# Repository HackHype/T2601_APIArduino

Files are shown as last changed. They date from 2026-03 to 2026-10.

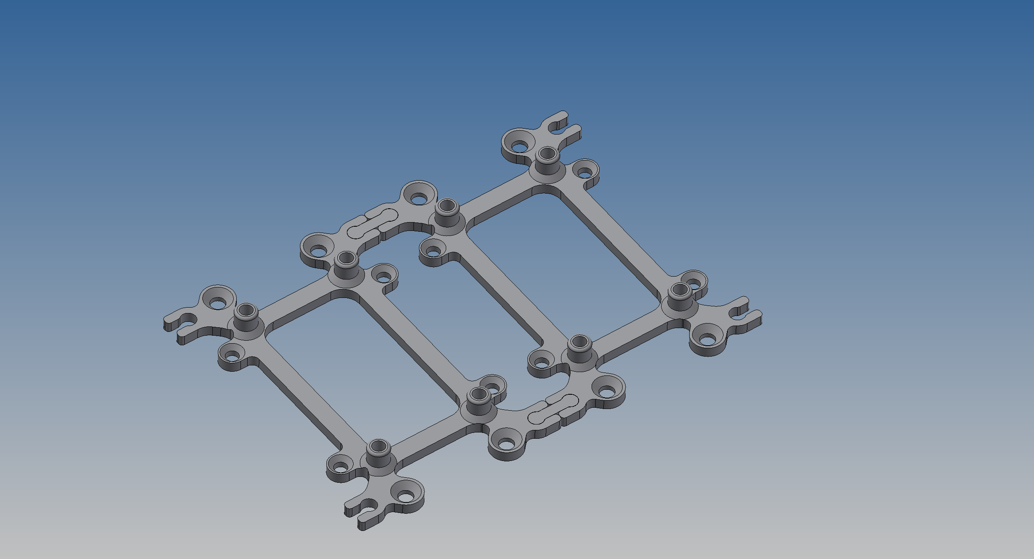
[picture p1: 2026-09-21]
T2601_Mecanique/T2601_EG2.png

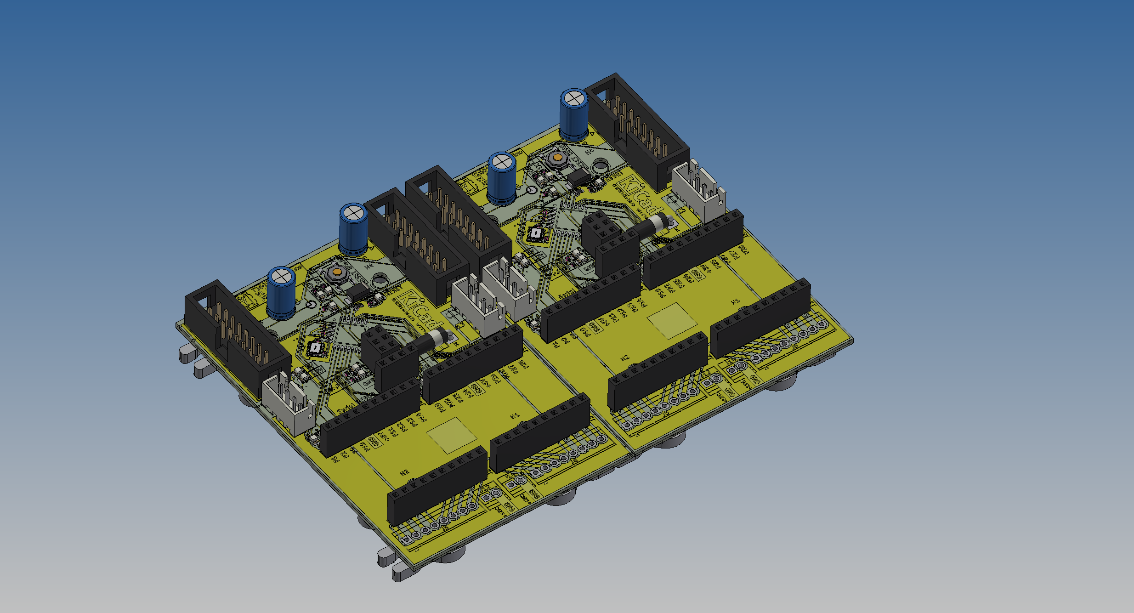
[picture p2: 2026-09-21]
T2601_Mecanique/T2601_EG.png

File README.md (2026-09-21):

# T2601 — API Arduino
> Modular I/O expansion board based on the ATmega328PB.






---

## System Architecture

### 🟦 Main Board
_Mother board of the system — orchestrates the entire bus_

- Hosts a compact dev board (Teensy-style)
- **3 Mezzanine slots** for I/O interface cards
- **N System Mezzanine slots** for advanced modules
  - FRAM / RTC / MicroSD / ... modules
- Power management for the entire system

---

### 🟩 Extension Board
_Bus slave node — based on the ATmega328P_

- Microcontroller: **ATmega328P**
- **2 Mezzanine slots** for I/O
- **Chained UART** communication across all extension boards
- Programming via **Arduino as ISP**

---

### 🟨 Mezzanine Card
_swappable I/O interface module — 25 × 25 mm_

| Driver | Type | Typical Use |
|---|---|---|
| ULN2803 | Sink NPN | Relays, inductive loads |
| MIC2981 | Source PNP  | High-voltage loads |
| MOSFET | Switch | Power loads |
| Voltage divider| Passive | Analog input |
| Optocoupler | Isolated | Galvanic isolation |

---

## Repository Structure
```
T2601_APIArduino/
├── hardware/
│   ├── main_board/        # Main board
│   ├── extension_board/   # ATmega328P extension board
│   └── mezzanine/         # I/O mezzanine cards
├── firmware/              # Arduino code
├── docs/                  # Schematics, datasheets
└── README.md
```

---

## License

This project is open hardware — **CERN OHL v2 Strongly Reciprocal**.

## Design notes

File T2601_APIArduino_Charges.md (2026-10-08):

# T2601 API Arduino

# Carte Extension

## Généralité

Basé sur microcontroler Atmega 328PB
Emplacement pour 2 mezanine.

## Connectivité

UART circulaire
Bus de logique avec nappe et connecteur de nappe 2x8  
4x 5V (pour 1,5 A), 6x GND, 2x UART (aller et retour), 1x rst, 1x res  
Bus puissance avec connecteurs JST  
2x 12V 2xGND (pour 2A)  
Les GND logique et puissance sont séparer  
Alimentation puissance par borniers à vis  
1x 12V 1xGND  
16 Sortie puissance par borniers à vis, 1 bornier par mezzanine  
Connexion pour la programmation par pin socket 2x3  
Connexion pour le debug (SoftwareSerial) par pin socket 1x4  
1x GND 1x TX 1x RX 1x statut

## Fonctionnalité

Led vertes sur chacune des alimentations  
Led jaune sur pin prog  
Led jaune sur RX TX  
Led vertes sur chacune des I/O  
Led rouge sur la dernière broche libre de l’arduino

## Pinout µc

|Pin|Fonction|Utilisation|
|-|-|-|
|1 |PWM |Mezz 1 (PWM)|
|2 | |led (couleur à définir) + generale debug pin|
|3 |SDA + |led (couleur à définir)|
|4 |VCC |Alimentation|
|5 |GND |Alimentation|
|6 |SCL |led (couleur à définir)|
|7 |XTAL1 |Crystal|
|8 |XTAL2 |Crystal|
|9 |PWM |Mezz 1 (PWM)|
|10|PWM AIN0 |Mezz 1 (PWM)|
|11|AIN1 |Mezz 1|
|12| |Mezz 1|
|13|PWM |Mezz 1 (PWM)|
|14|PWM SS |Mezz 1 (PWM)|
|15|MOSI TXD1 +|Programmation|
|16|MISO RXD1  |Programmation|
|17|SCK |Programmation|
|18|AVCC |Alimentation|
|19|ADC6 SS1 |Mezz 2 (Analog)|
|20|AREF |Alimentation|
|21|GND |Alimentation|
|22|ADC7 MOSI1 |Mezz 2 (Analog)|
|23|ADC0 MISO1 |Mezz 2 (Analog)|
|24|ADC1 SCK1  |Mezz 2 (Analog)|
|25|ADC2 |Mezz 2 (Analog)|
|26|ADC3 |Mezz 2 (Analog)|
|27|ADC4 SDA |Mezz 2 (Analog)|
|28|ADC5 SCL |Mezz 2 (Analog)|
|29|Reset||
|30|RXD PWM |Communication|
|31|TXD PWM |Communication|
|32|PWM + |Mezz 1 (PWM)|

_+ : d'autre fonction sont disponibles mais pas utilisées_

_les interruptions ne sont pas notées dans les fonctions_

## Mécanique

Largeur 60, Hauteur 90 à définir
4 trous pour vis M3 avec un entraxe de 30 en largeur, à 10 du bord suppérieur et à 20 du bord inférieur.

# Mezanine

1 connecteur pin header male 1x10
1x GND, 1x 5V, 8x logique,  
1 connecteur pin socket femelle 1x10  
1x GND, 1x 12V, 8x puissance,

## Types

* OUTPUT

  * ULN2803
  * MIC2981
  * Mosfet
  * Optocoupleur
  * Pont (5V direct)
* INPUT

  * Pont diviseur 12/24V
  * Pont (5V direct)
  * Optocoupleur (autre sens)
* IO

  * Loconet (nécessite ICP pin)
  * Carte SD + RTC (nécessite SPI ou I2C)
  * RS485 (nécessite Software serial)
  * FRAM (nécessite SPI ou I2C)

## communication (idée)

Commandes envoyée ddans le Bus

|Champs|Taille \[bit]|
|-|-|
|Contrôle|8|
|Adresse noeud|8|
|Adresse registre|8|
|longeur donnée|8|
|Donnée|8 - 2048|

Champ contrôles

|7  - 4|3 - 2|1 - 0|
|-|-|-|
|version protocole (idée)|destinations spéciales|commande|

destinations spéciales :

* Normales
* Prochain noeud
* Broadcast (tous)
* Adresses allongées (idée...)

commandes :

* Lire
* Ecrire
* Annoncer

Adresse de noeud spéciales
0x00 : maître

avoir un groupe de potentiellement 127 ou 256 "registre" qui peuvent être lu ou écrit

|premier|nombre|fonciton|
|-|-|-|
|0|16|paramètre généraux de la carte (type, adresse,...)|
|16|16|paramètres spécifiques au type de carte|
|32|16|typiquement, un registre par pin pour analog ou pour PWM|
|48|16|typiquement, un registre par pin pour analog ou pour PWM|
|64|64 ou 192|divers|

# Carte Principale

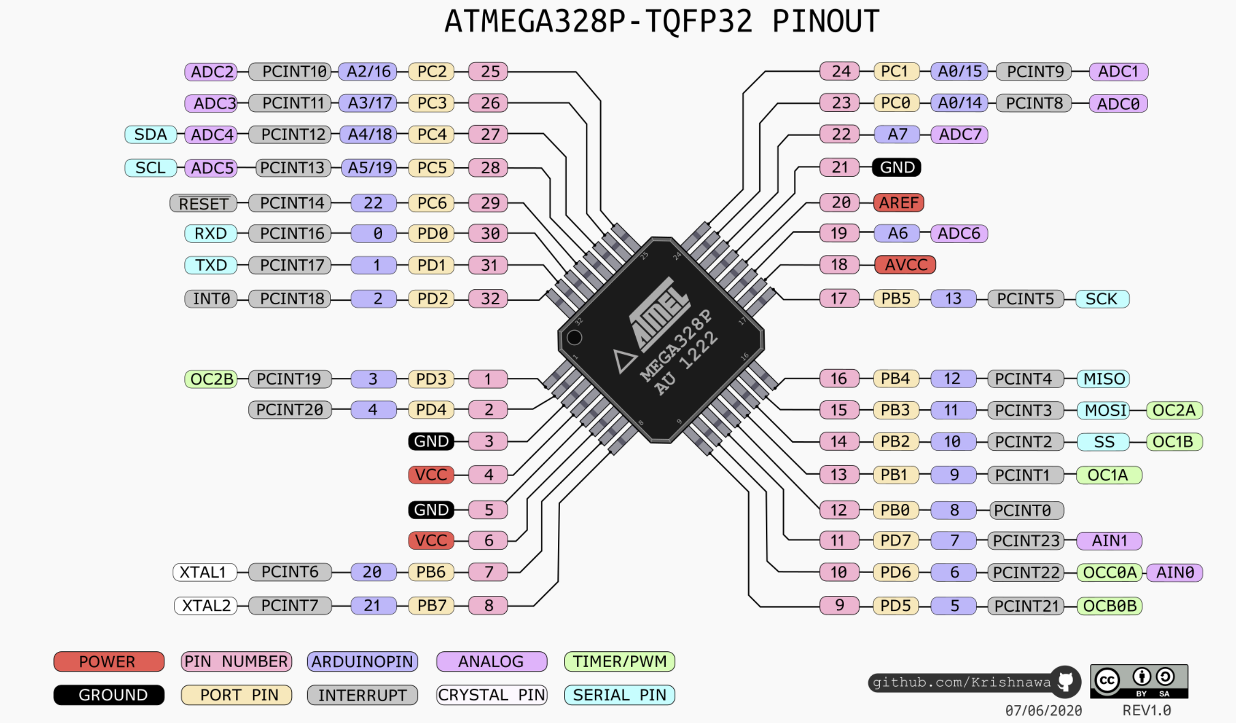
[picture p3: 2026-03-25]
Documentation/Atmega 328P - TQNF32 PinOut.png

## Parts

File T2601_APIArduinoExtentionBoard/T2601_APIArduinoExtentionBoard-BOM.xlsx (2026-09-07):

BOM - PCB Extention Board API Arduino
Quoi | Variante | Ref PCB | Valeur | Reference | Qty/PCB | Qty/Tot | Prix | PrixTot/PCB | Fabriquant | Fournisseur | Lien
Pin Header Male |  |  | 1x10 | P2.54mm | 4 |  | 0.21 CHF | 0.84 CHF |  | Aliexpress | https://de.aliexpress.com/item/1005005917096107.html
Pin Header Female |  |  | 1x10 | P2.54mm | 4 |  | 0.15 CHF | 0.60 CHF |  | Aliexpress | https://de.aliexpress.com/item/1005007813499880.html
Pin Header Female |  |  | 2x3 | P2.54mm | 1 |  | 0.18 CHF | 0.18 CHF |  | Aliexpress | https://de.aliexpress.com/item/1005011642464715.html
Connecteur Cable Plat Male |  |  | 2x8 | P2.54mm | 2 |  | 0.27 CHF | 0.54 CHF |  | Aliexpress | https://de.aliexpress.com/item/1005005509699672.html
Connecteur XH Male |  |  | 1x4 | XH P2.54mm | 2 |  | 0.06 CHF | 0.11 CHF |  | Aliexpress | https://de.aliexpress.com/item/1005002864663115.html
Connecteur XH Femelle |  |  | 1x4 | XH P2.54mm | 2 |  | 0.03 CHF | 0.06 CHF |  | Aliexpress | https://de.aliexpress.com/item/1005012223211250.html
Fil Précerti pour XH |  |  | SECTION |  | 4 |  |  | 0.00 CHF |  | Aliexpress
Cable Plat |  |  | 8x0,14mm2 |  | 1 |  |  | 0.00 CHF |  | Conrad
ScrewTerminal |  |  | 1x2 | P2.54mm | 2 |  |  | 0.00 CHF |  | Aliexpress
ScrewTerminal |  |  | 1x8 | P2.54mm | 2 |  |  | 0.00 CHF |  | Aliexpress
Condensateur |  |  |  |  |  |  |  | 0.00 CHF |  | Stock
 |  |  |  |  |  |  |  | 0.00 CHF
 |  |  |  |  |  |  |  | 0.00 CHF
 |  |  |  |  |  |  |  | 0.00 CHF
 |  |  |  |  |  |  |  | 0.00 CHF
 |  |  |  |  |  |  |  | 0.00 CHF
 |  |  |  |  |  |  |  | 0.00 CHF
 |  |  |  |  |  |  |  | 0.00 CHF
 |  |  |  |  |  |  |  | 0.00 CHF
 |  |  |  |  |  |  |  | 0.00 CHF
 |  |  |  |  |  |  |  | 0.00 CHF
 |  |  |  |  |  |  |  | 0.00 CHF
 |  |  |  |  |  |  |  | 0.00 CHF
 |  |  |  |  |  |  |  | 0.00 CHF
 |  |  |  |  |  |  |  | 0.00 CHF
 |  |  |  |  |  |  |  | 0.00 CHF
 |  |  |  |  |  |  |  | 0.00 CHF
 |  |  |  |  |  |  |  | 0.00 CHF
 |  |  |  |  |  |  |  | 0.00 CHF
 |  |  |  |  |  |  |  | 0.00 CHF
 |  |  |  |  |  |  |  | 0.00 CHF
 |  |  |  |  |  |  |  | 0.00 CHF
 |  |  |  |  |  |  |  | 0.00 CHF
Date : |  | 2026-08-14 | #VALUE!
Auteur : |  | Jules Grucy
Revision : |  | V1
Approbateur : |  | Damien De P.

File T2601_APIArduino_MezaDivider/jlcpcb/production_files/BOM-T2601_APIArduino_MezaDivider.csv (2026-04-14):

Comment | Designator | Footprint | LCSC | Quantity
5.1kΩ | R10,R11,R12,R13,R14,R15,R16,R9 | R_0603 | C23186 | 8
7.5kΩ | R1,R2,R3,R4,R5,R6,R7,R8 | R_0603 | C23234 | 8

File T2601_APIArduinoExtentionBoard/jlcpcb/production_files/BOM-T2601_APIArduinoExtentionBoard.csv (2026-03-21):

Comment | Designator | Footprint | LCSC | Quantity
100nF | C3,C4 | C_0402 | C1525 | 2
1kΩ | R24,R25 | R_0603 | C21190 | 2
2.4kΩ | R23 | R_0603 | C22940 | 1
22pF | C1,C2 | C_0402 | C1555 | 2
5.6kΩ | R5 | R_0603 | C23189 | 1
510Ω | R1,R10,R11,R12,R13,R14,R15,R16,R17,R18,R19,R2,R20,R21,R22,R3,R4,R6,R7,R8,R9 | R_0402 | C25123 | 21
ATMEGA328P-AU | U1 | TQFP-32_L7.0-W7.0-P0.80-LS9.0-BL | C14877 | 1
Green | D14,D15,D16,D17,D18,D19,D2,D20,D21,D22,D23,D24,D25,D3,D4,D5,D7,D8 | D_0805 | C2297 | 18
M7 | D6 | D_SMA | C95872 | 1
Red | D13,D26 | D_0805 | C84256 | 2
Tactile Button, 160gf | S1 | SW-SMD_4P-L5.1-W5.1-P3.70-LS6.5-TL-2 | C318884 | 1
X322516MOB4SI | X1 | CRYSTAL-SMD_4P-L3.2-W2.5-BL | C12668 | 1
Yellow | D10,D11,D12,D9 | D_0805 | C2296 | 4
Screw_Terminal_01x08 | J5 | TerminalBlock_TE_282834-8_1x08_P2.54mm_Horizontal |  | 1
Screw_Terminal_01x02 | J14 | TerminalBlock_Xinya_XY308-2.54-2P_1x02_P2.54mm_Horizontal |  | 1
Conn_01x10_Socket | J2 | PinSocket_1x10_P2.54mm_Vertical |  | 1
Conn_02x03_Counter_Clockwise | J7 | PinSocket_2x03_P2.54mm_Vertical |  | 1
Conn_01x10_Socket | J3 | PinSocket_1x10_P2.54mm_Vertical |  | 1
Conn_01x04_Pin | J13 | JST_XH_B4B-XH-A_1x04_P2.50mm_Vertical |  | 1
Conn_01x04 | J8 | PinSocket_1x04_P2.54mm_Vertical |  | 1
Conn_01x10_Socket | J1 | PinSocket_1x10_P2.54mm_Vertical |  | 1
Screw_Terminal_01x02 | J12 | TerminalBlock_Xinya_XY308-2.54-2P_1x02_P2.54mm_Horizontal |  | 1
Conn_02x08_Counter_Clockwise | J9 | IDC-Header_2x08_P2.54mm_Vertical |  | 1
Screw_Terminal_01x08 | J6 | TerminalBlock_TE_282834-8_1x08_P2.54mm_Horizontal |  | 1
Conn_01x10_Socket | J4 | PinSocket_1x10_P2.54mm_Vertical |  | 1
D_Schottky | D1 | D_5W_P12.70mm_Horizontal |  | 1
Conn_01x04_Pin | J11 | JST_XH_B4B-XH-A_1x04_P2.50mm_Vertical |  | 1
Conn_02x08_Counter_Clockwise | J15 | IDC-Header_2x08_P2.54mm_Vertical |  | 1

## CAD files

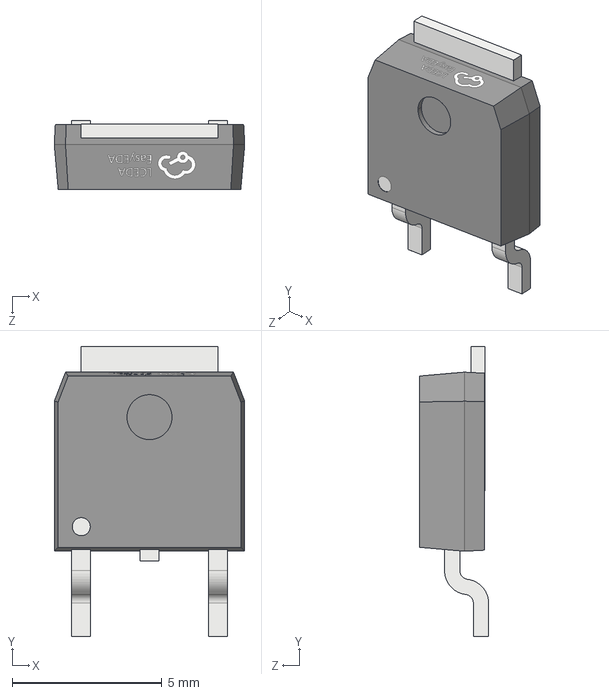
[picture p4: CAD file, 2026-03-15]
T2601_APIArduinoExtentionBoard/M2601_APIArduinoExtentionBoard_Lib3D/TO-252-3_L6.5-W5.8-P4.58-BL.step
6.35 x 9.67 x 2.31 mm

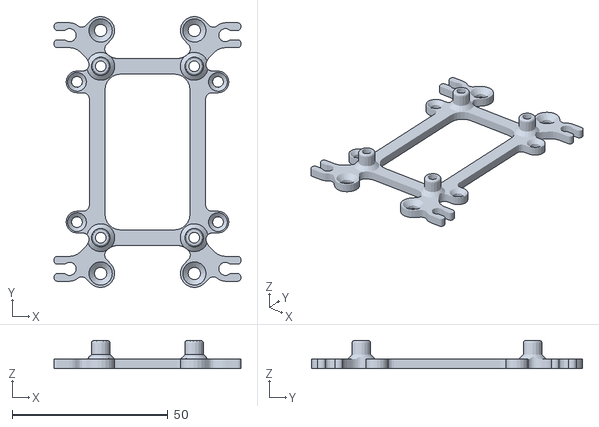
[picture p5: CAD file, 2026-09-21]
T2601_Mecanique/T2601_BaseP30.obj
60.0 x 87.0 x 9.00

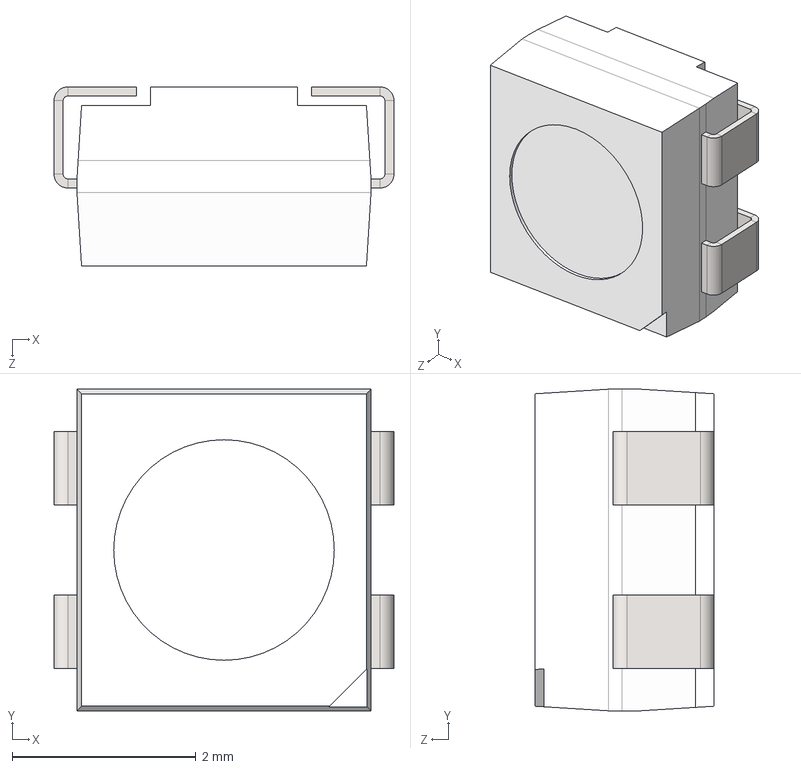
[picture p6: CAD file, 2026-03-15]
T2601_APIArduinoExtentionBoard/M2601_APIArduinoExtentionBoard_Lib3D/LED-SMD_4P-L3.5-W3.5-BR_SK6812MINI-HS.step
3.70 x 3.50 x 1.95 mm

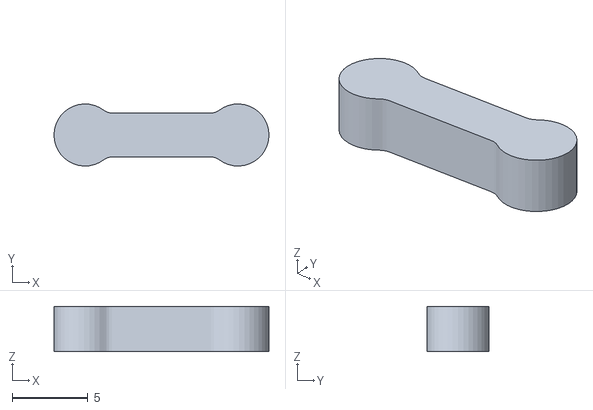
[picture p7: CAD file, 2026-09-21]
T2601_Mecanique/T2601_Conn.obj
14.2 x 4.10 x 3.00

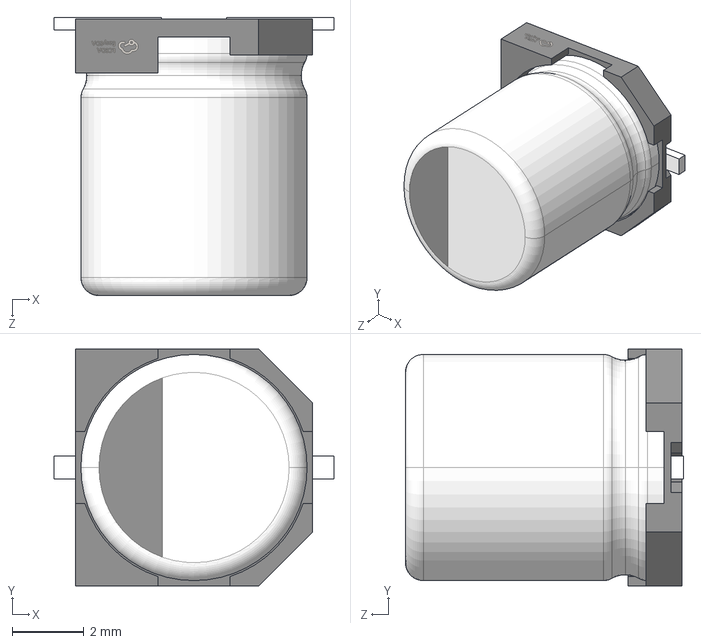
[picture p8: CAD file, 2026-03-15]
T2601_APIArduinoExtentionBoard/M2601_APIArduinoExtentionBoard_Lib3D/CAP-SMD_BD6.3-L6.6-W6.6-FD.step
7.80 x 6.60 x 7.75 mm

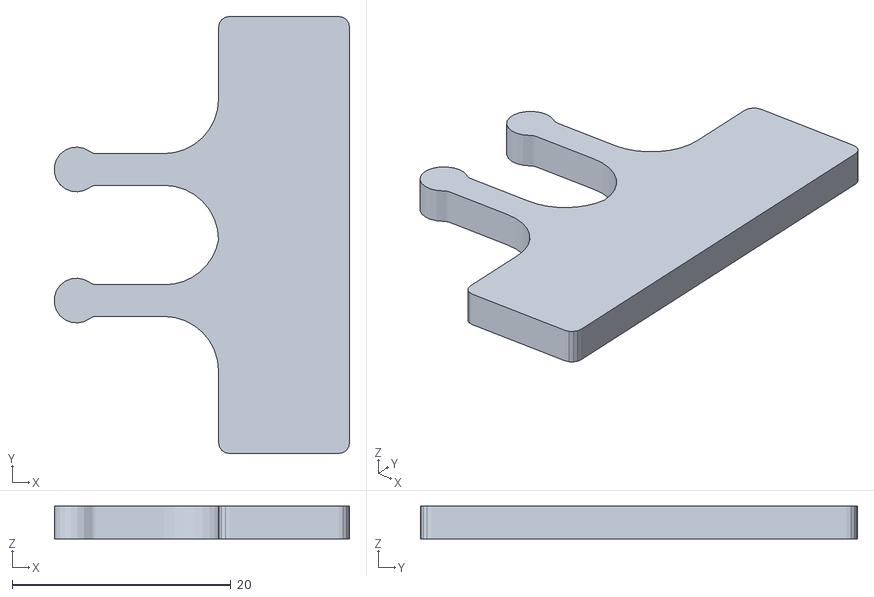
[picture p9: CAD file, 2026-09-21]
T2601_Mecanique/T2601_SupportEtiq.obj
27.0 x 40.0 x 3.00

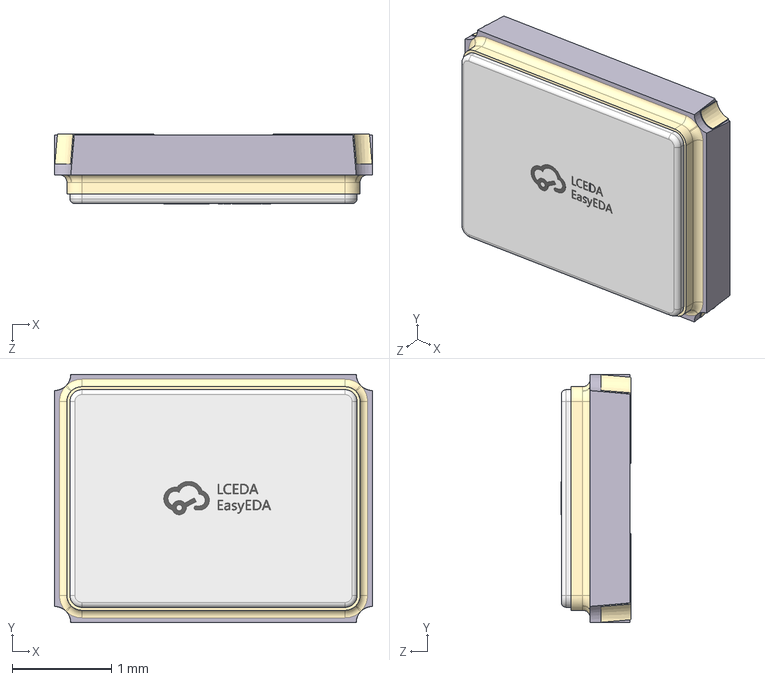
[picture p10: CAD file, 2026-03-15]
T2601_APIArduinoExtentionBoard/M2601_APIArduinoExtentionBoard_Lib3D/CRYSTAL-SMD_4P-L3.2-W2.5-BL.step
3.20 x 2.50 x 0.701 mm

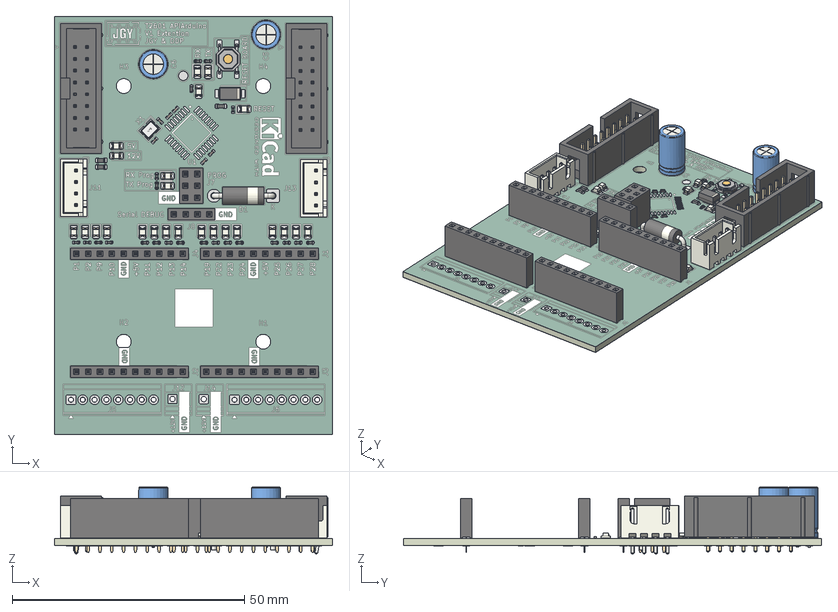
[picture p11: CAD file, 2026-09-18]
T2601_Mecanique/T2601_ExtentionBoard.step
59.8 x 90.0 x 14.4 mm
R_0402 x 22
R_0603 x 3
IDC-Header_2x08_P2.54mm_Vertical x 2
D_0805 x 24
C_0402 x 6
C_Radial_D6.3mm_H11.0mm_P2.50mm x 2
PinSocket_1x10_P2.54mm_Vertical x 4
PinSocket_2x03_P2.54mm_Vertical
JST_XH_B4B-XH-A_1x04_P2.50mm_Vertical x 2
PinSocket_1x04_P2.54mm_Vertical
D_SMA
CRYSTAL-SMD_4P-L3.2-W2.5-BL
SW-SMD_4P-L5.1-W5.1-P3.70-LS6.5-TL-2
D_5W_P12.70mm_Horizontal
T2601_APIArduinoExtentionBoard_copper
T2601_APIArduinoExtentionBoard_pad
T2601_APIArduinoExtentionBoard_via
T2601_APIArduinoExtentionBoard_silkscreen x 2
T2601_APIArduinoExtentionBoard_soldermask x 2
T2601_APIArduinoExtentionBoard_PCB

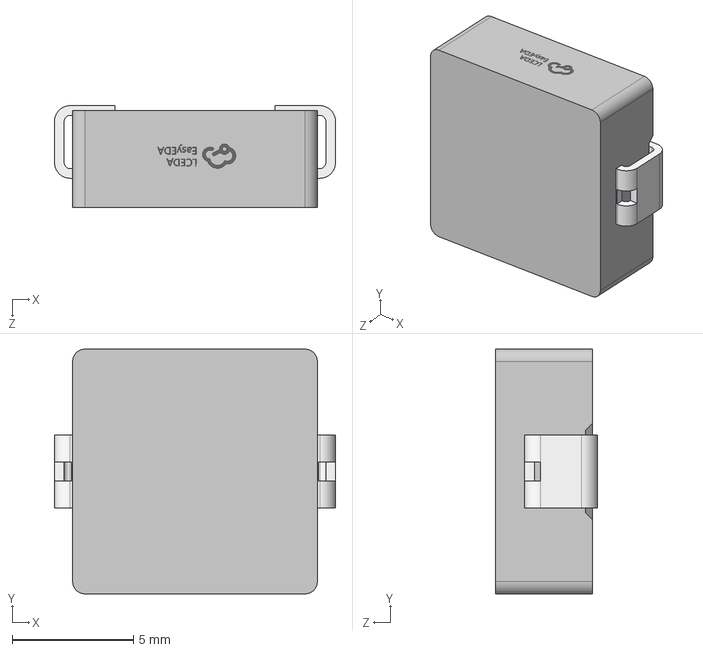
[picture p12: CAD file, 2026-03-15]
T2601_APIArduinoExtentionBoard/M2601_APIArduinoExtentionBoard_Lib3D/IND-SMD_L11.6-W10.1-H4.0.step
11.6 x 10.1 x 4.20 mm

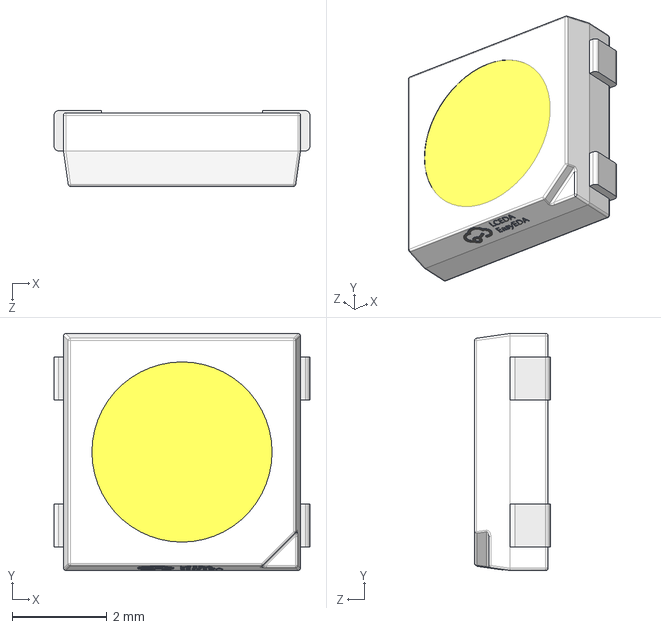
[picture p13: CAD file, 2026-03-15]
T2601_APIArduinoExtentionBoard/M2601_APIArduinoExtentionBoard_Lib3D/LED-SMD_4P-L5.4-W5.0_SK6112-RG.step
5.40 x 5.00 x 1.60 mm

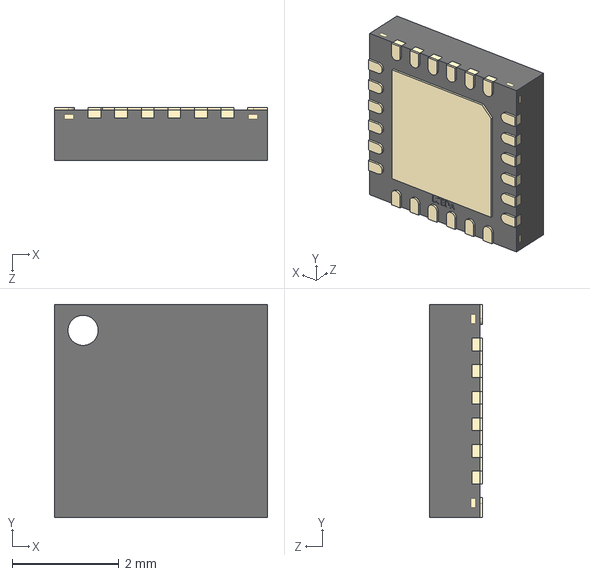
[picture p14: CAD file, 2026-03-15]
T2601_APIArduinoExtentionBoard/M2601_APIArduinoExtentionBoard_Lib3D/VQFN-24_L4.0-W4.0-P0.50-TL-EP2.7.step
4.00 x 4.00 x 1.00 mm

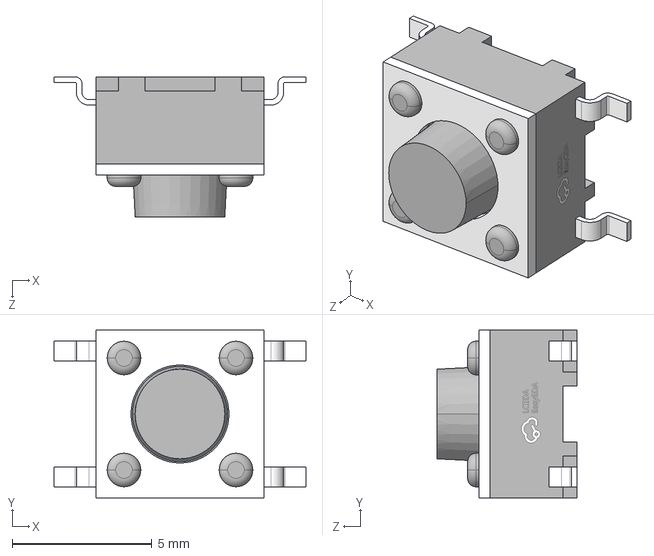
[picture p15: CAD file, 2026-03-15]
T2601_APIArduinoExtentionBoard/M2601_APIArduinoExtentionBoard_Lib3D/KEY-SMD_4P-L6.0-W6.0-P4.50-LS9.5-BL.step
9.00 x 6.00 x 5.01 mm

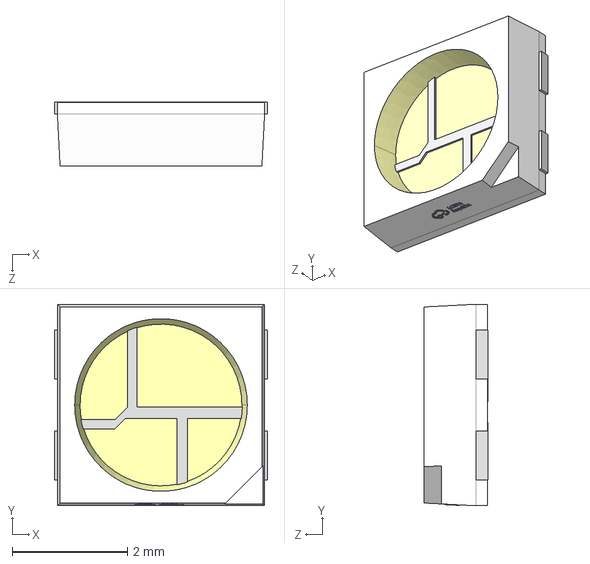
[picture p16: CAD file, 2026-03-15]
T2601_APIArduinoExtentionBoard/M2601_APIArduinoExtentionBoard_Lib3D/LED-SMD_4P-L3.7-W3.5-P1.75-BR-SK6812MINI.step
3.70 x 3.50 x 1.11 mm

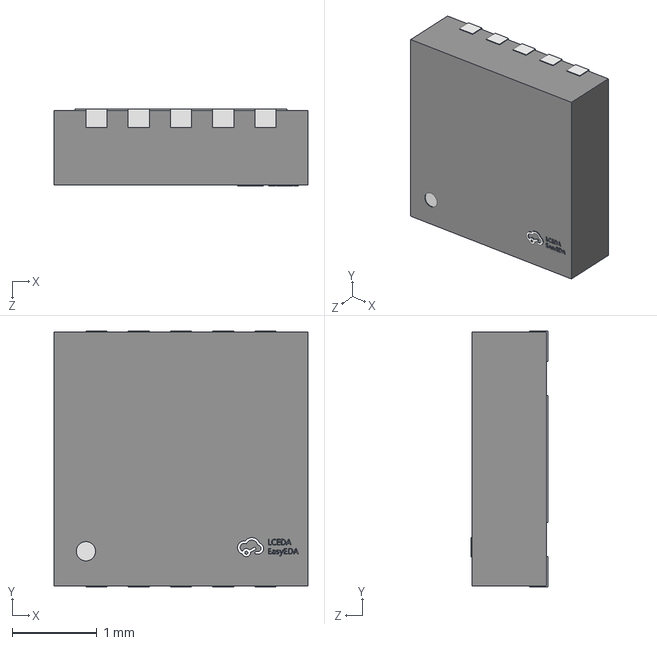
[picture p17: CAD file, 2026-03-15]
T2601_APIArduinoExtentionBoard/M2601_APIArduinoExtentionBoard_Lib3D/DFN-10_L3.0-W3.0-P0.50-BL-EP2.5.step
3.00 x 3.02 x 0.91 mm

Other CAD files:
T2601_APIArduinoExtentionBoard/M2601_APIArduinoExtentionBoard_Lib3D/CAP-SMD_L4.3-W4.3-H5.3-LS5.1.step
T2601_APIArduinoExtentionBoard/M2601_APIArduinoExtentionBoard_Lib3D/USB-C-SMD_HC-TYPE-C-16P-01A.step
T2601_APIArduinoExtentionBoard/M2601_APIArduinoExtentionBoard_Lib3D/HTSSOP-16_L5.0-W4.4-P0.65-LS6.4-BL-EP2.5.step
T2601_APIArduinoExtentionBoard/M2601_APIArduinoExtentionBoard_Lib3D/HTSSOP-20_L6.5-W4.4-P0.65-LS6.4-BL-EP3.0.step
T2601_APIArduinoExtentionBoard/M2601_APIArduinoExtentionBoard_Lib3D/CAP-SMD_BD6.3-L6.6-W6.6-H7.7.step
T2601_APIArduinoExtentionBoard/M2601_APIArduinoExtentionBoard_Lib3D/IND-SMD_L5.0-W5.0-LQH5BPN1R5NT0L.step
T2601_APIArduinoExtentionBoard/M2601_APIArduinoExtentionBoard_Lib3D/QFN-16_L3.0-W3.0-H0.9-P0.50.step
T2601_Mecanique/T2601_BaseP30.ipt
T2601_Mecanique/T2601_Conn.ipt
T2601_Mecanique/T2601_EG.iam
T2601_Mecanique/T2601_ExtentionBoard/T2601_BaseP30.ipt
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

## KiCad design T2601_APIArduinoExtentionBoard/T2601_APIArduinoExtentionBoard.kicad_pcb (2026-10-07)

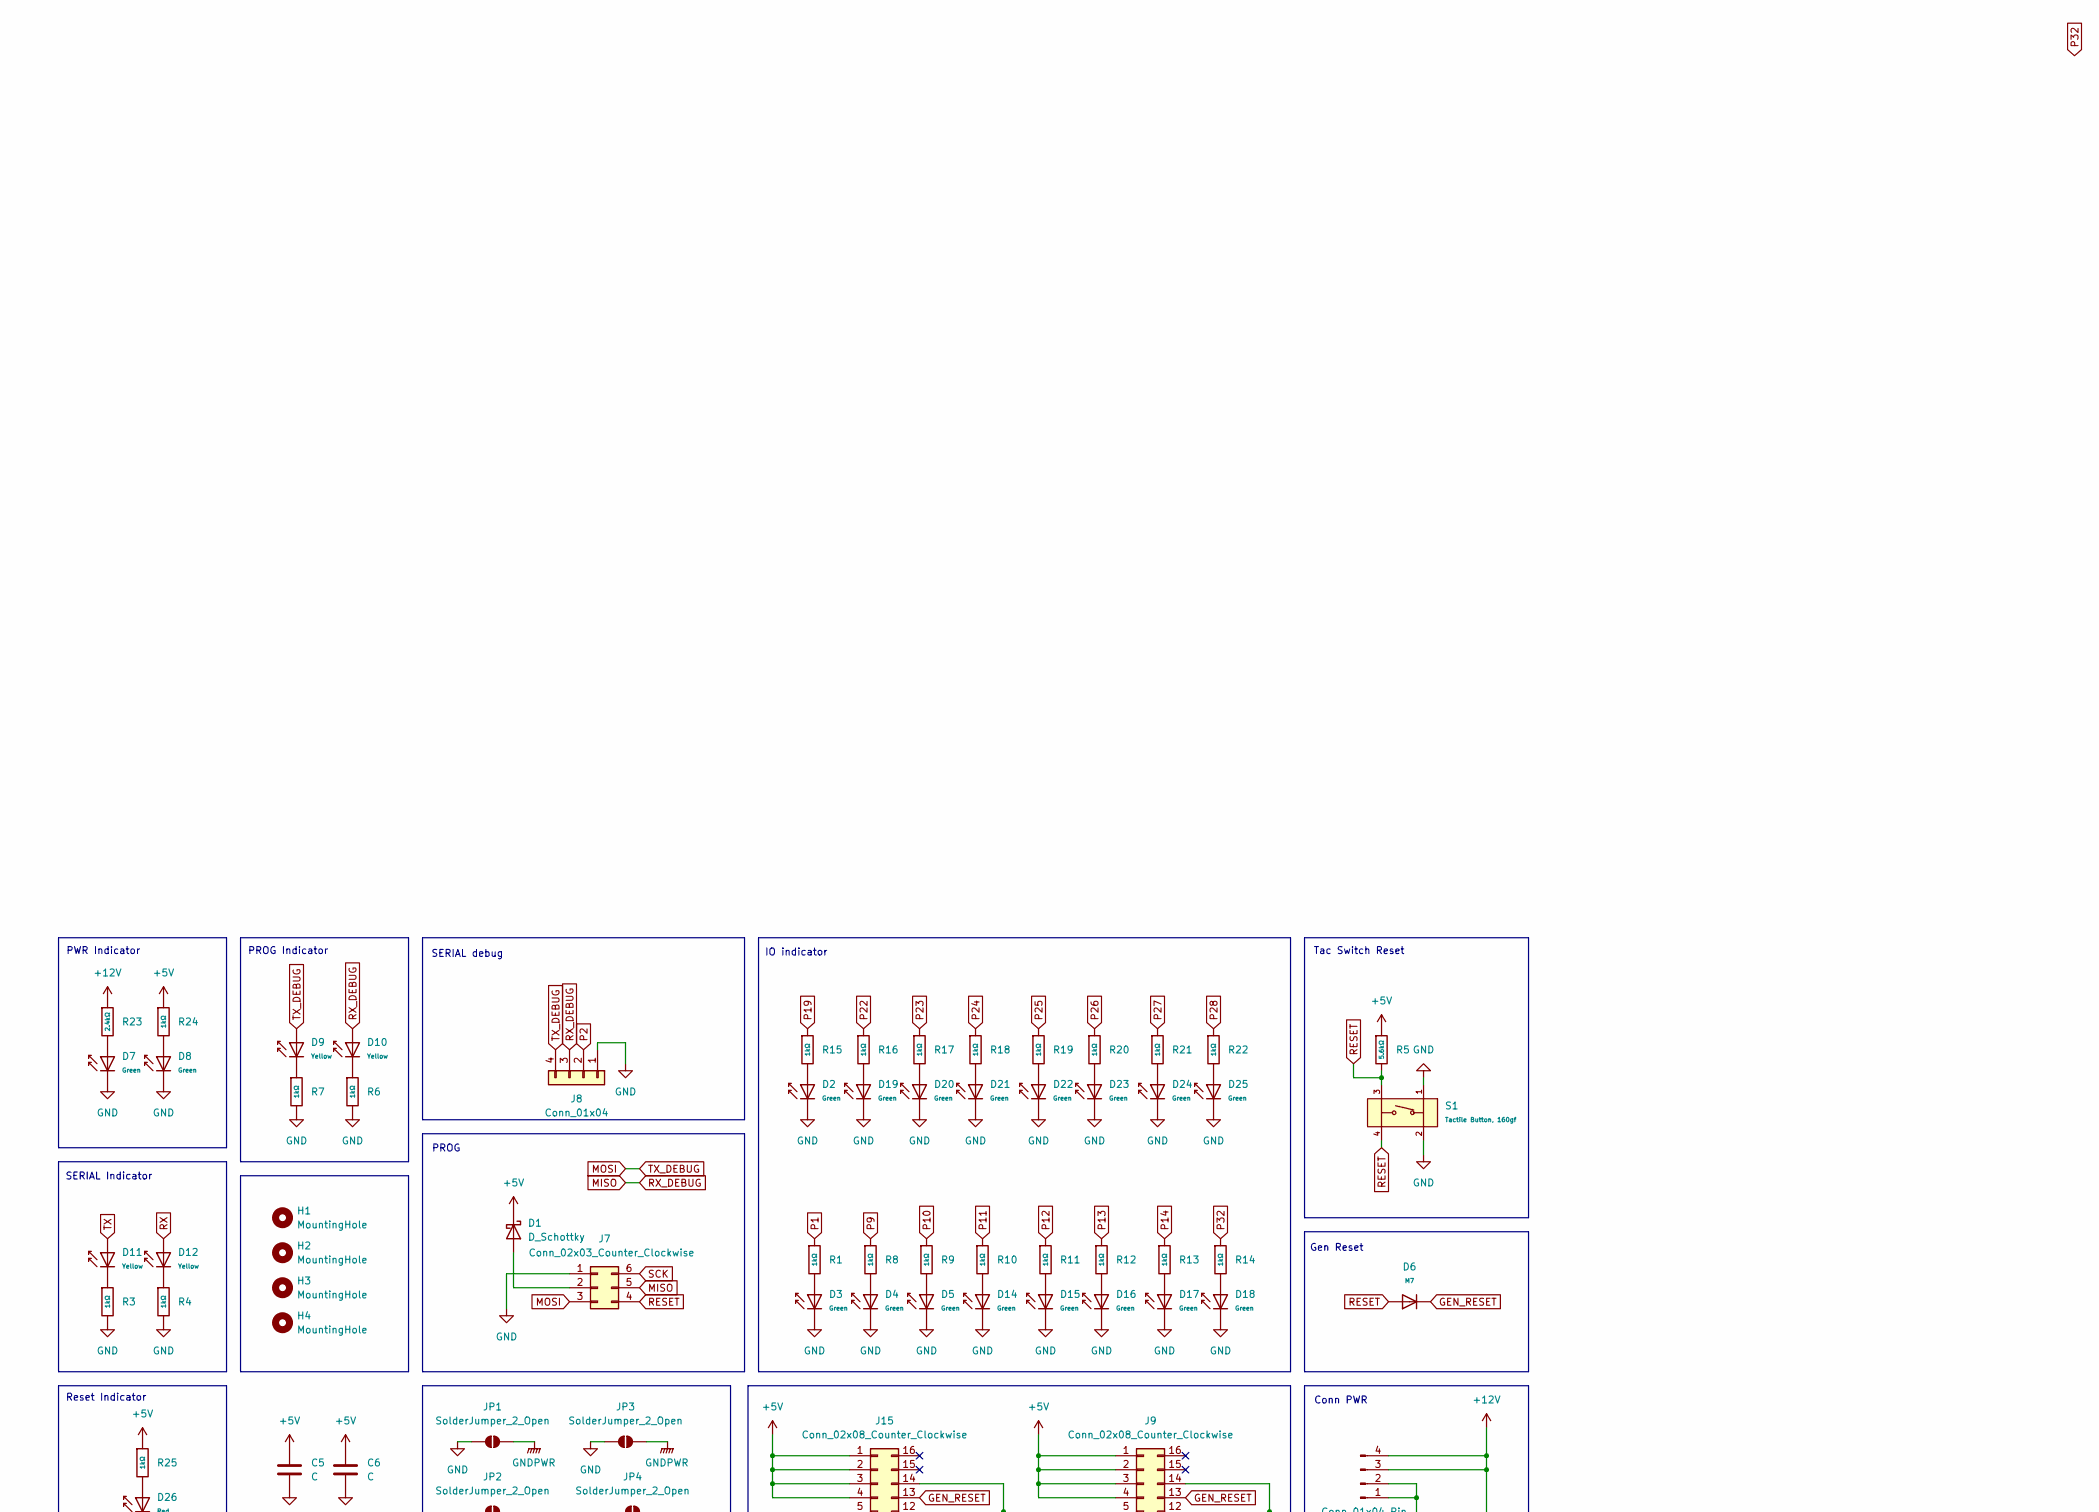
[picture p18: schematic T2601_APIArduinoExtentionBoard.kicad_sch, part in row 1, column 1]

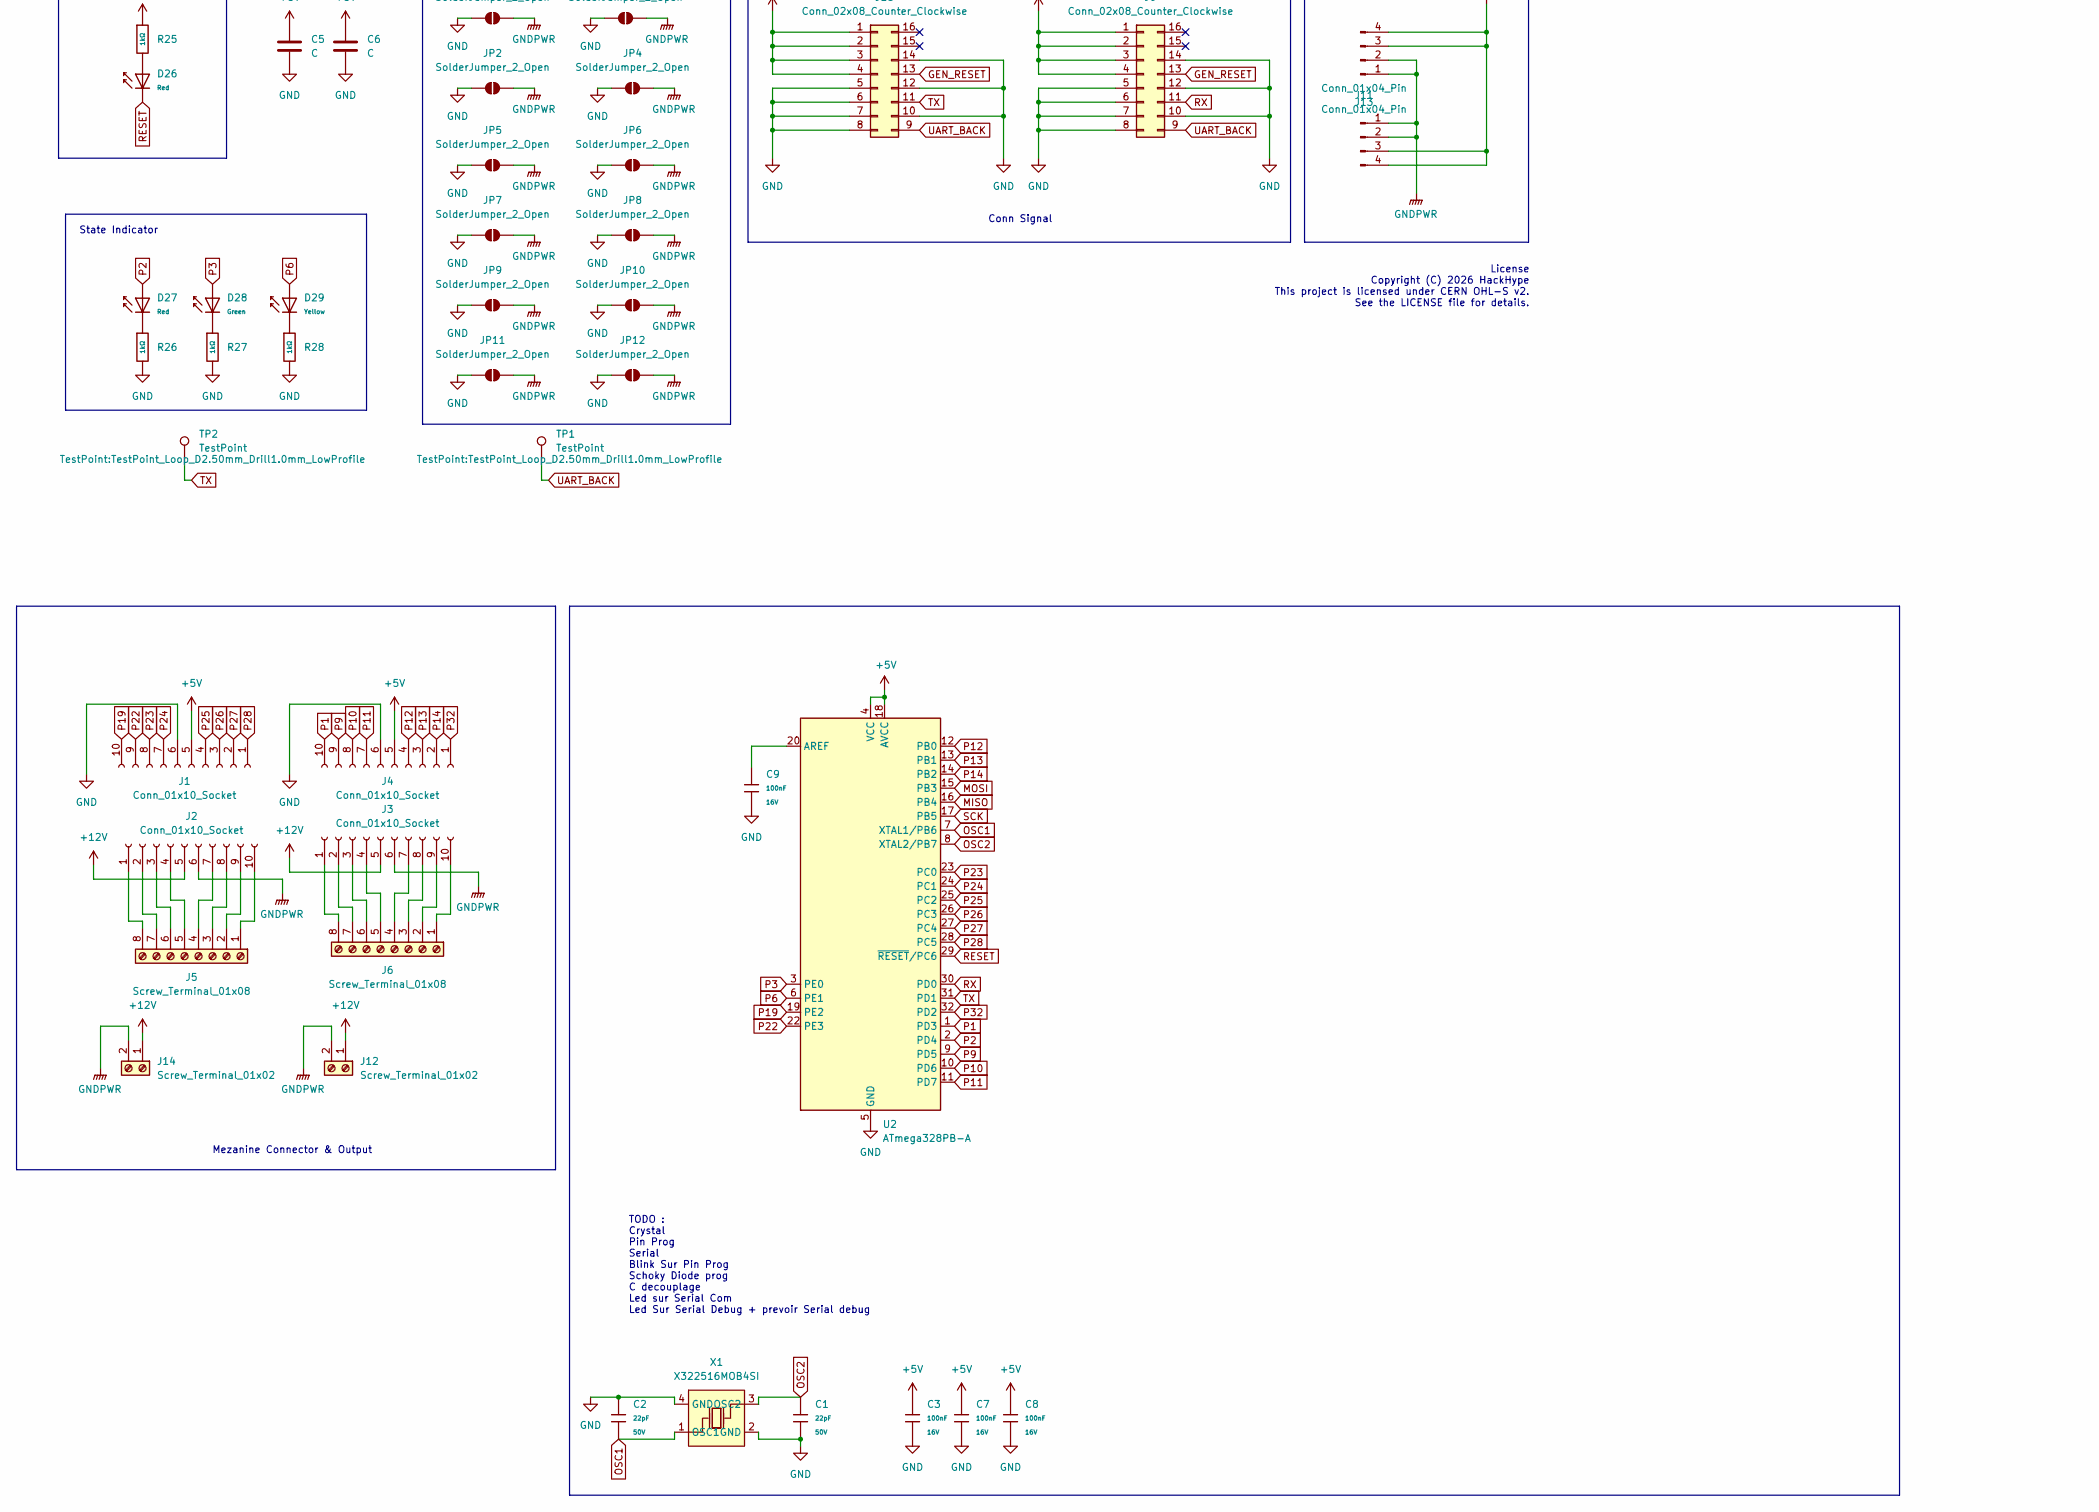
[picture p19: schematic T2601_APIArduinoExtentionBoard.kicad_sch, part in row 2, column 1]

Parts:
C1, C2: 22pF; C_0402; Voltage Rated 50V; Tolerance ±5%; Part 0402CG220J500NT; LCSC C1555
C3, C7, C8, C9: 100nF; C_0402; Voltage Rated 16V; Tolerance ±10%; Part CL05B104KO5NNNC; LCSC C1525
C5, C6: C; C_Radial_D6.3mm_H11.0mm_P2.50mm
D1: D_Schottky; D_5W_P12.70mm_Horizontal
D2, D3, D4, D5, D7, D8, D14, D15, D16, D17, D18, D19, D20, D21, D22, D23, D24, D25, D28: Green; D_0805; Part KT-0805G; LCSC C2297
D6: M7; D_SMA; Forward Voltage (Vf@If) 1.1V@1A; Reverse Voltage (Vr) 1kV; Part M7; LCSC C95872
D9, D10, D11, D12, D29: Yellow; D_0805; Part KT-0805Y; LCSC C2296
D26, D27: Red; D_0805; Forward Voltage (VF) 1.6V~2.6V; Part NCD0805R1; LCSC C84256
H1, H2, H3, H4: MountingHole; MountingHole_3.2mm_M3
J1, J2, J3, J4: Conn_01x10_Socket; PinSocket_1x10_P2.54mm_Vertical
J5, J6: Screw_Terminal_01x08; TerminalBlock_TE_282834-8_1x08_P2.54mm_Horizontal
J7: Conn_02x03_Counter_Clockwise; PinSocket_2x03_P2.54mm_Vertical
J8: Conn_01x04; PinSocket_1x04_P2.54mm_Vertical
J9, J15: Conn_02x08_Counter_Clockwise; IDC-Header_2x08_P2.54mm_Vertical
J11, J13: Conn_01x04_Pin; JST_XH_B4B-XH-A_1x04_P2.50mm_Vertical
J12, J14: Screw_Terminal_01x02; TerminalBlock_Xinya_XY308-2.54-2P_1x02_P2.54mm_Horizontal
JP1, JP2, JP3, JP4, JP5, JP6, JP7, JP8, JP9, JP10, JP11, JP12: SolderJumper_2_Open; SolderJumper-2_P1.3mm_Open_RoundedPad1.0x1.5mm
R1, R3, R4, R6, R7, R8, R9, R10, R11, R12, R13, R14, R15, R16, R17, R18, R19, R20, R21, R22, R25, R26, R27, R28: 1kΩ; R_0402; Overload Voltage (Max) 50V; Tolerance ±1%; Part 0402WGF1001TCE; LCSC C11702
R5: 5.6kΩ; R_0603; Overload Voltage (Max) 75V; Tolerance ±1%; Part 0603WAF5601T5E; LCSC C23189
R23: 2.4kΩ; R_0603; Overload Voltage (Max) 75V; Tolerance ±1%; Part 0603WAF2401T5E; LCSC C22940
R24: 1kΩ; R_0603; Overload Voltage (Max) 75V; Tolerance ±1%; Part 0603WAF1001T5E; LCSC C21190
S1: Tactile Button, 160gf; SW-SMD_4P-L5.1-W5.1-P3.70-LS6.5-TL-2; Voltage Rating (Dc) 12V; Part TS-1187A-B-A-B; LCSC C318884
TP1, TP2: TestPoint; TestPoint_Loop_D2.50mm_Drill1.0mm_LowProfile
U2: ATmega328PB-A; TQFP-32_7x7mm_P0.8mm
X1: X322516MOB4SI; CRYSTAL-SMD_4P-L3.2-W2.5-BL; LCSC Part C12668

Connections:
+5V: C3.1, C5.1, C6.1, C7.1, C8.1, D1.1 (K), J1.5, J4.5, J9.1, J9.2, J9.3, J9.4, J15.1, J15.2, J15.3, J15.4, R5.1, R24.1, R25.1, U2.4 (VCC), U2.18 (AVCC)
+12V: J2.5, J3.5, J11.3, J11.4, J12.1, J13.3, J13.4, J14.1, R23.1
GEN_RESET: D6.1, J9.13, J15.13
GND: C1.2, C2.1, C3.2, C5.2, C6.2, C7.2, C8.2, C9.2, D2.1, D3.1, D4.1, D5.1, D7.1, D8.1, D14.1, D15.1, D16.1, D17.1, D18.1, D19.1, D20.1, D21.1, D22.1, D23.1, D24.1, D25.1, J1.6, J4.6, J7.1, J8.1, J9.5, J9.6, J9.7, J9.8, J9.10, J9.12, J9.14, J15.5, J15.6, J15.7, J15.8, J15.10, J15.12, J15.14, JP1.1 (A), JP2.1 (A), JP3.1 (A), JP4.1 (A), JP5.1 (A), JP6.1 (A), JP7.1 (A), JP8.1 (A), JP9.1 (A), JP10.1 (A), JP11.1 (A), JP12.1 (A), R3.2, R4.2, R6.2, R7.2, R26.2, R27.2, R28.2, S1.1 (A), S1.2 (B), U2.5 (GND), U2.21 (GND), X1.2 (GND), X1.4 (GND)
GNDPWR: J2.6, J3.6, J11.1, J11.2, J12.2, J13.1, J13.2, J14.2, JP1.2 (B), JP2.2 (B), JP3.2 (B), JP4.2 (B), JP5.2 (B), JP6.2 (B), JP7.2 (B), JP8.2 (B), JP9.2 (B), JP10.2 (B), JP11.2 (B), JP12.2 (B)
MISO: D10.2, J7.5, J8.3, U2.16 (PB4)
MOSI: D9.2, J7.3, J8.4, U2.15 (PB3)
unnamed: D1.2 (A), J7.2
unnamed: D2.2, R15.2
unnamed: D3.2, R1.2
unnamed: D4.2, R8.2
unnamed: D5.2, R9.2
unnamed: D7.2, R23.2
unnamed: D8.2, R24.2
unnamed: D9.1, R7.1
unnamed: D10.1, R6.1
unnamed: D11.1, R3.1
unnamed: D12.1, R4.1
unnamed: D14.2, R10.2
unnamed: D15.2, R11.2
unnamed: D16.2, R12.2
unnamed: D17.2, R13.2
unnamed: D18.2, R14.2
unnamed: D19.2, R16.2
unnamed: D20.2, R17.2
unnamed: D21.2, R18.2
unnamed: D22.2, R19.2
unnamed: D23.2, R20.2
unnamed: D24.2, R21.2
unnamed: D25.2, R22.2
unnamed: D26.2, R25.2
unnamed: D27.1, R26.1
unnamed: D28.1, R27.1
unnamed: D29.1, R28.1
unnamed: J2.1, J5.8
unnamed: J2.2, J5.7
unnamed: J2.3, J5.6
unnamed: J2.4, J5.5
unnamed: J2.7, J5.4
unnamed: J2.8, J5.3
unnamed: J2.9, J5.2
unnamed: J2.10, J5.1
unnamed: J3.1, J6.8
unnamed: J3.2, J6.7
unnamed: J3.3, J6.6
unnamed: J3.4, J6.5
unnamed: J3.7, J6.4
unnamed: J3.8, J6.3
unnamed: J3.9, J6.2
unnamed: J3.10, J6.1
unnamed: C9.1, U2.20 (AREF)
OSC1: C2.2, U2.7 (XTAL1/PB6), X1.1 (OSC1)
OSC2: C1.1, U2.8 (XTAL2/PB7), X1.3 (OSC2)
P1: J4.10, R1.1, U2.1 (PD3)
P2: D27.2, J8.2, U2.2 (PD4)
P3: D28.2, U2.3 (PE0)
P6: D29.2, U2.6 (PE1)
P9: J4.9, R8.1, U2.9 (PD5)
P10: J4.8, R9.1, U2.10 (PD6)
P11: J4.7, R10.1, U2.11 (PD7)
P12: J4.4, R11.1, U2.12 (PB0)
P13: J4.3, R12.1, U2.13 (PB1)
P14: J4.2, R13.1, U2.14 (PB2)
P19: J1.10, R15.1, U2.19 (PE2)
P22: J1.9, R16.1, U2.22 (PE3)
P23: J1.8, R17.1, U2.23 (PC0)
P24: J1.7, R18.1, U2.24 (PC1)
P25: J1.4, R19.1, U2.25 (PC2)
P26: J1.3, R20.1, U2.26 (PC3)
P27: J1.2, R21.1, U2.27 (PC4)
P28: J1.1, R22.1, U2.28 (PC5)
P32: J4.1, R14.1, U2.32 (PD2)
RESET: D6.2, D26.1, J7.4, R5.2, S1.3 (C), S1.4 (D), U2.29 (~RESET/PC6)
RX: D12.2, J9.11, U2.30 (PD0)
SCK: J7.6, U2.17 (PB5)
TX: D11.2, J15.11, TP2.1 (1_1), U2.31 (PD1)
UART_BACK: J9.9, J15.9, TP1.1 (1_1)

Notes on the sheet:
Gen Reset
PROG
PROG Indicator
IO indicator
TODO : Crystal Pin Prog Serial Blink Sur Pin Prog Schoky Diode prog C decouplage Led sur Serial Com Led Sur Serial Debug + prevoir Serial debug
Conn PWR
PWR Indicator
SERIAL debug
Mezanine Connector & Output
State Indicator
License Copyright (C) 2026 HackHype This project is licensed under CERN OHL-S v2. See the LICENSE file for details.
Tac Switch Reset
Reset Indicator
SERIAL Indicator
Conn Signal

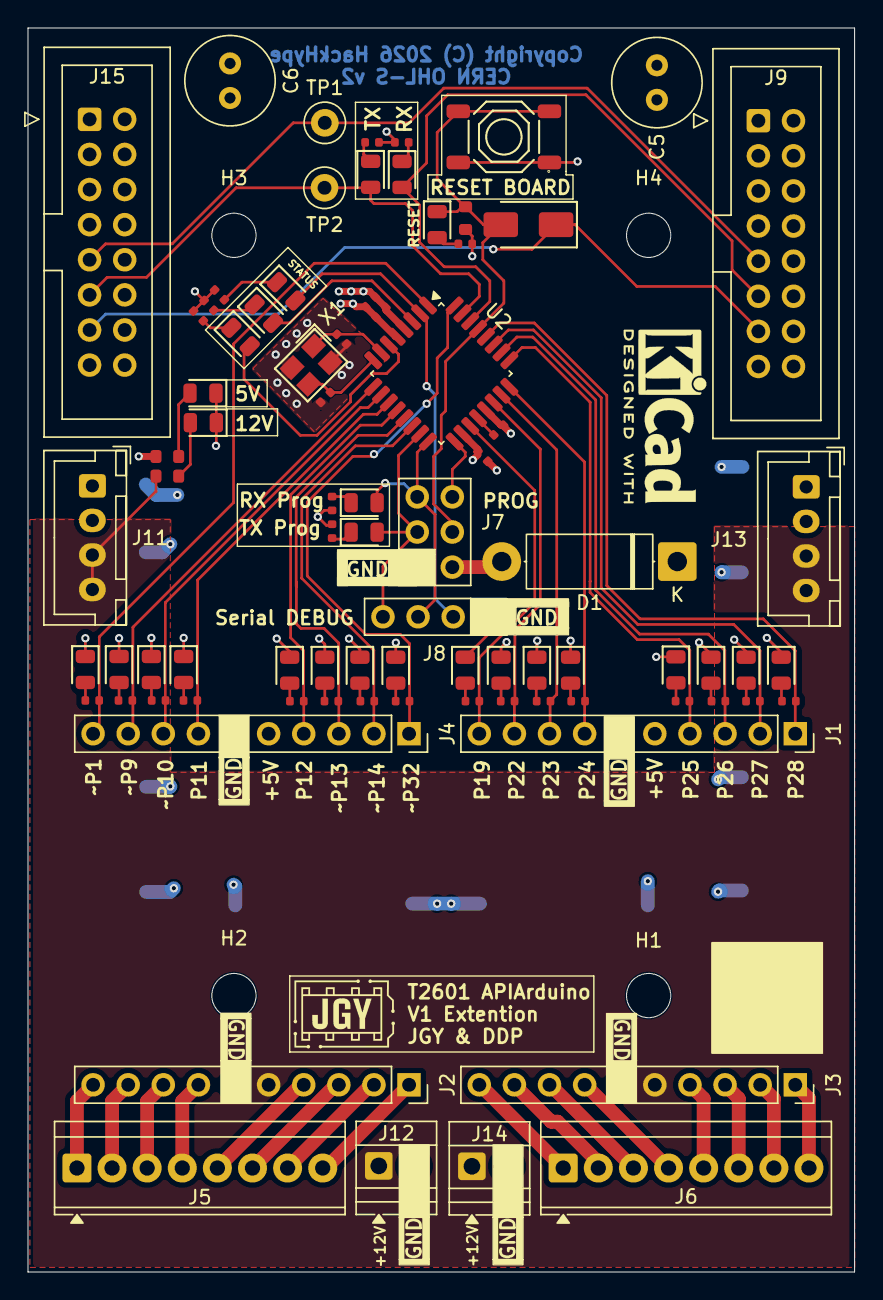
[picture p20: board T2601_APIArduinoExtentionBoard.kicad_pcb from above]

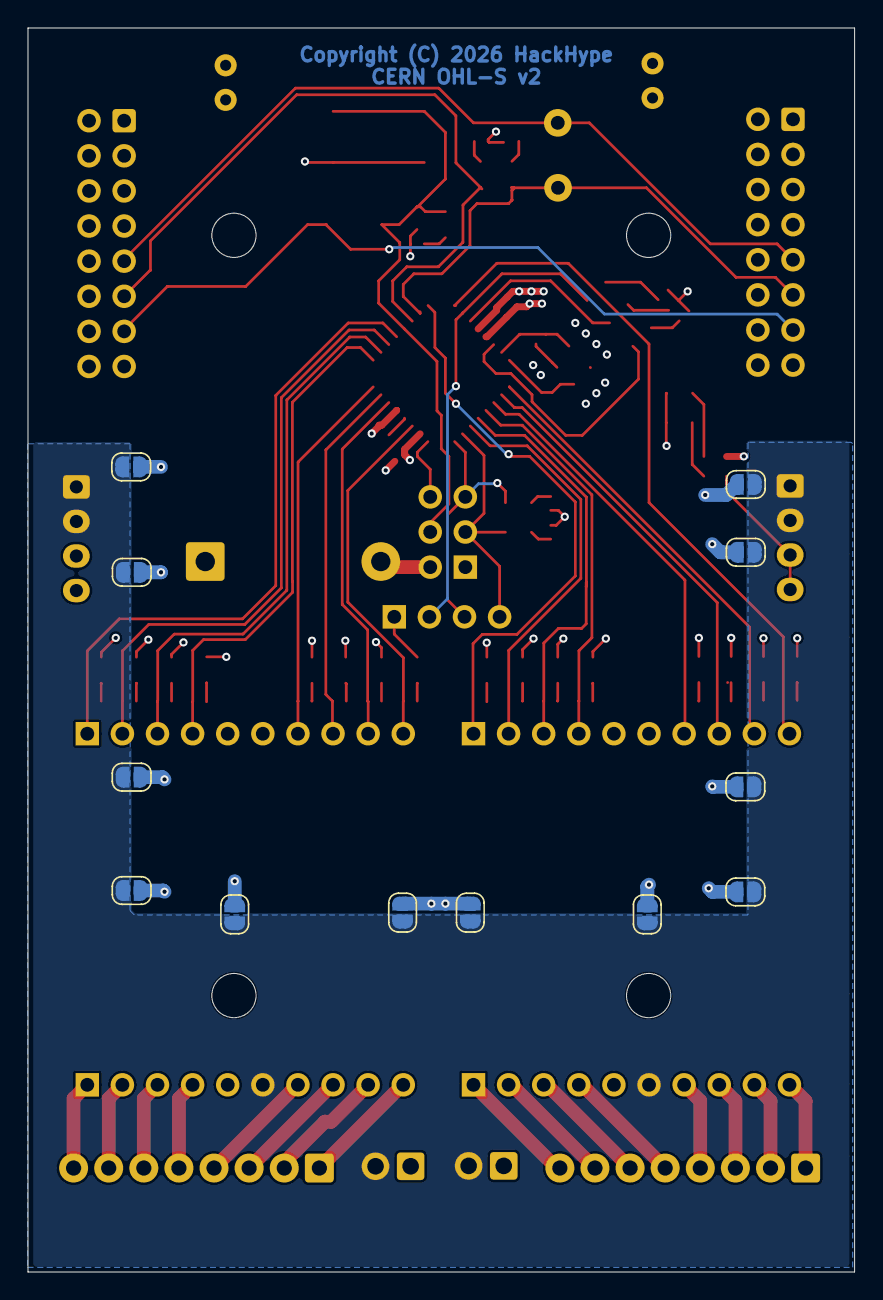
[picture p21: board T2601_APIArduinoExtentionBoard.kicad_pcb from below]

Board: 4 copper layers, 59.8 x 90.0 mm, 98 parts (12 on the bottom side), 77 nets.

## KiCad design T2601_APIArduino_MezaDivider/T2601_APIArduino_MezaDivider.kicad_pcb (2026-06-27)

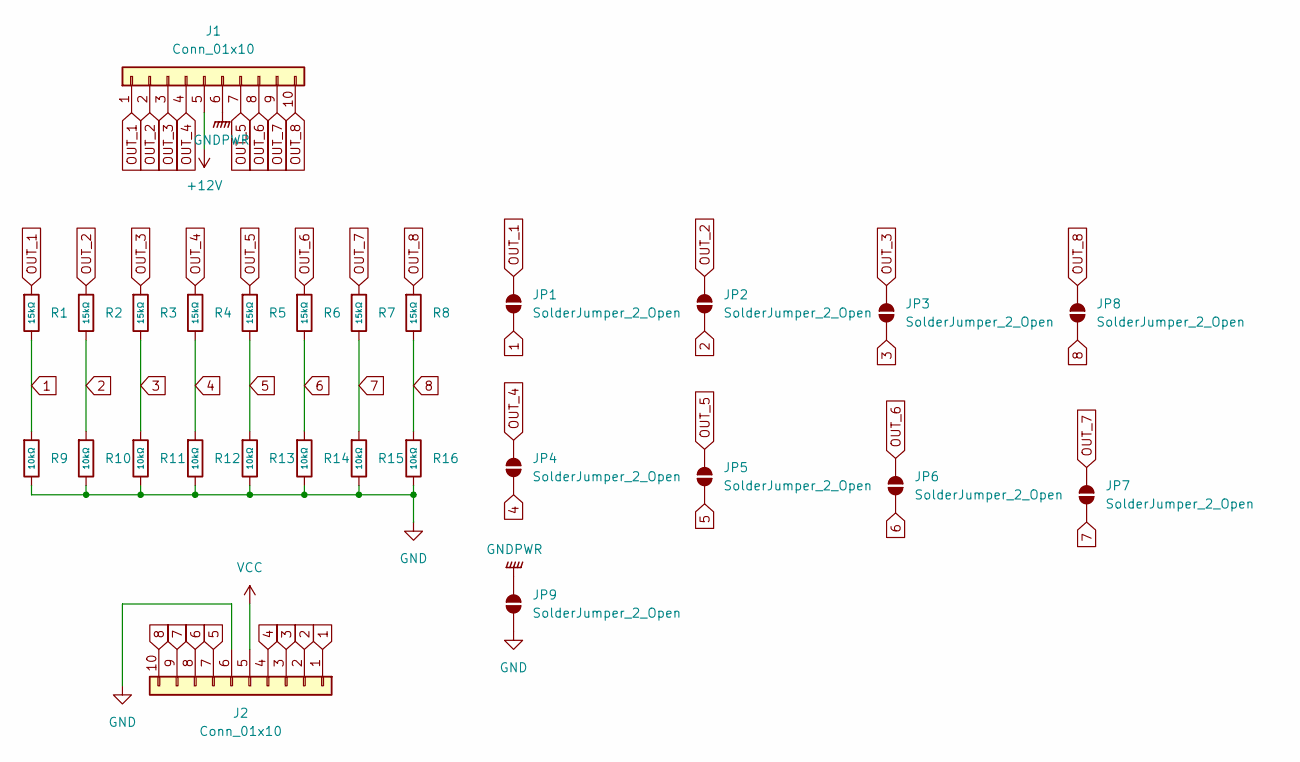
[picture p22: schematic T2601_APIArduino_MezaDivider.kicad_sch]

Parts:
J1, J2: Conn_01x10; PinHeader_1x10_P2.54mm_Vertical
JP1, JP2, JP3, JP4, JP5, JP6, JP7, JP8, JP9: SolderJumper_2_Open; SolderJumper-2_P1.3mm_Open_RoundedPad1.0x1.5mm
R1, R2, R3, R4, R5, R6, R7, R8: 15kΩ; R_0402; Overload Voltage (Max) 50V; Tolerance ±1%; Part 0402WGF1502TCE; LCSC C25756
R9, R10, R11, R12, R13, R14, R15, R16: 10kΩ; R_0402; Overload Voltage (Max) 50V; Tolerance ±1%; Part 0402WGF1002TCE; LCSC C25744

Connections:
1: J2.1, JP1.1 (A), R1.2, R9.1
2: J2.2, JP2.1 (A), R2.2, R10.1
3: J2.3, JP3.1 (A), R3.2, R11.1
4: J2.4, JP4.1 (A), R4.2, R12.1
5: J2.7, JP5.1 (A), R5.2, R13.1
6: J2.8, JP6.1 (A), R6.2, R14.1
7: J2.9, JP7.1 (A), R7.2, R15.1
8: J2.10, JP8.1 (A), R8.2, R16.1
+12V: J1.5
GND: J2.6, JP9.1 (A), R9.2, R10.2, R11.2, R12.2, R13.2, R14.2, R15.2, R16.2
GNDPWR: J1.6, JP9.2 (B)
OUT_1: J1.1, JP1.2 (B), R1.1
OUT_2: J1.2, JP2.2 (B), R2.1
OUT_3: J1.3, JP3.2 (B), R3.1
OUT_4: J1.4, JP4.2 (B), R4.1
OUT_5: J1.7, JP5.2 (B), R5.1
OUT_6: J1.8, JP6.2 (B), R6.1
OUT_7: J1.9, JP7.2 (B), R7.1
OUT_8: J1.10, JP8.2 (B), R8.1
VCC: J2.5

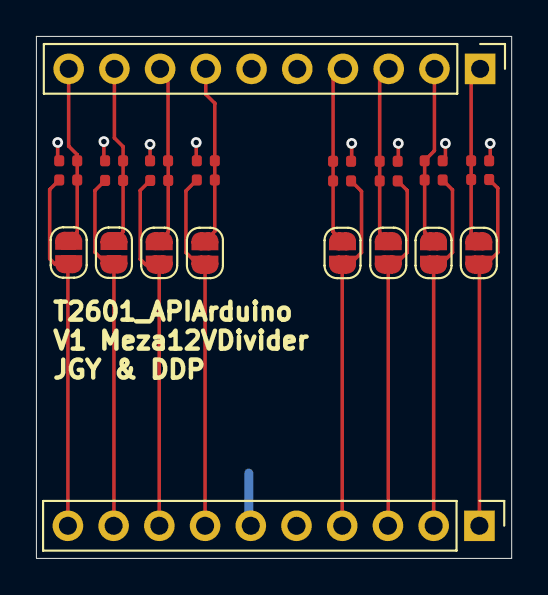
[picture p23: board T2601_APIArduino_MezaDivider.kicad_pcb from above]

Board: 2 copper layers, 26.4 x 29.0 mm, 27 parts (1 on the bottom side), 18 nets.

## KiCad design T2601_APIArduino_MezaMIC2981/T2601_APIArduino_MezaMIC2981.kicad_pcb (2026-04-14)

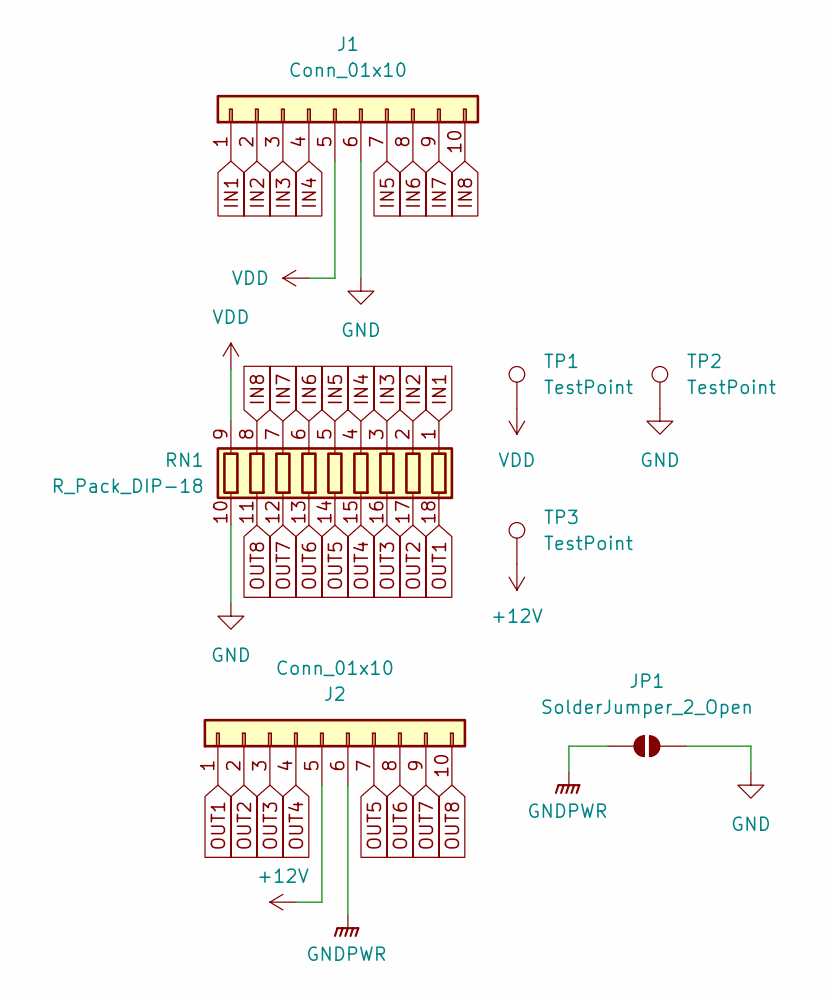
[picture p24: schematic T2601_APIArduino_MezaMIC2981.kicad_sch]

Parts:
J1, J2: Conn_01x10; PinHeader_1x10_P2.54mm_Vertical
JP1: SolderJumper_2_Open; SolderJumper-2_P1.3mm_Open_RoundedPad1.0x1.5mm
RN1: R_Pack_DIP-18; DIP-18_W7.62mm_Socket_LongPads
TP1, TP2, TP3: TestPoint; TestPoint_Pad_D1.5mm

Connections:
+12V: J2.5, TP3.1
GND: J1.6, JP1.2 (B), RN1.10 (R9.2), TP2.1
GNDPWR: J2.6, JP1.1 (A)
IN1: J1.1, RN1.1 (R1.1)
IN2: J1.2, RN1.2 (R2.1)
IN3: J1.3, RN1.3 (R3.1)
IN4: J1.4, RN1.4 (R4.1)
IN5: J1.7, RN1.5 (R5.1)
IN6: J1.8, RN1.6 (R6.1)
IN7: J1.9, RN1.7 (R7.1)
IN8: J1.10, RN1.8 (R8.1)
OUT1: J2.1, RN1.18 (R1.2)
OUT2: J2.2, RN1.17 (R2.2)
OUT3: J2.3, RN1.16 (R3.2)
OUT4: J2.4, RN1.15 (R4.2)
OUT5: J2.7, RN1.14 (R5.2)
OUT6: J2.8, RN1.13 (R6.2)
OUT7: J2.9, RN1.12 (R7.2)
OUT8: J2.10, RN1.11 (R8.2)
VDD: J1.5, RN1.9 (R9.1), TP1.1

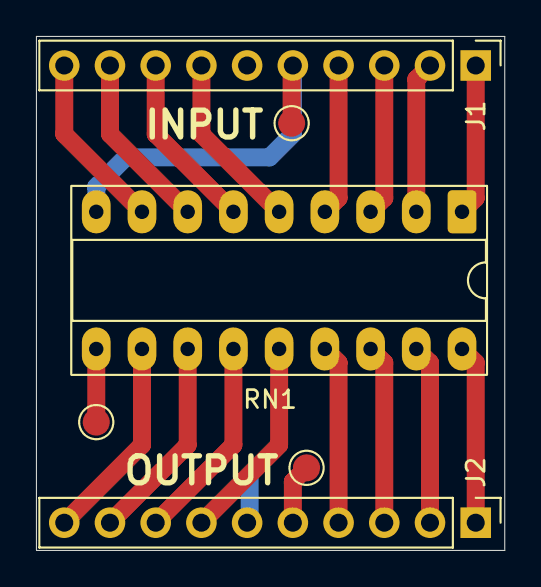
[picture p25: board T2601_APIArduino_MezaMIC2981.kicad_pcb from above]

Board: 2 copper layers, 26.0 x 28.6 mm, 7 parts (1 on the bottom side), 20 nets.

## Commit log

2026-03-15 remplacer charges word par md
2026-03-15 ajout position mountingholes
2026-03-15 V0.5 - Mounting Hole + Silkscreen
    [T2601_APIArduinoExtentionBoard.kicad_pcb, T2601_APIArduinoExtentionBoard.kicad_sch]
2026-03-15 Silkescreen Mod
    [T2601_APIArduinoExtentionBoard.kicad_pcb, T2601_APIArduinoExtentionBoard.kicad_sch]
2026-03-16 Pitch Header + Silkscreen
    [T2601_APIArduinoExtentionBoard.kicad_pcb]
2026-03-20 Silkscreen/Logo/ComPin Attribution
    [T2601_APIArduinoExtentionBoard.kicad_pcb, T2601_APIArduinoExtentionBoard.kicad_sch]
2026-03-21 3D models
    [BOM-T2601_APIArduinoExtentionBoard.csv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]
2026-03-25 Side Tolerances + Resistor Value
    [T2601_APIArduinoExtentionBoard.kicad_pcb, T2601_APIArduinoExtentionBoard.kicad_sch]
2026-03-25 Capacitor + plane correction
    [T2601_APIArduinoExtentionBoard.kicad_pcb, T2601_APIArduinoExtentionBoard.kicad_sch]
2026-03-25 Move C3
    [T2601_APIArduinoExtentionBoard.kicad_pcb]
2026-03-26 Decouppling capacitor, Oscilator
    [T2601_APIArduinoExtentionBoard.kicad_pcb]
2026-04-14 Mazzanine Bridge Divider
    [BOM-T2601_APIArduino_MezaDivider.csv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]
2026-06-27 Mezza Divider V1
    [T2601_APIArduinoExtentionBoard.kicad_pcb, T2601_APIArduino_MezaDivider.kicad_pcb, T2601_APIArduino_MezaDivider.kicad_sch]
2026-06-27 Meza Divider V1.1
    [T2601_APIArduino_MezaDivider.kicad_pcb]
2026-08-14 BOM V0
    [T2601_APIArduinoExtentionBoard-BOM.xlsx, T2601_APIArduinoExtentionBoard.kicad_sch]
2026-08-14 Forgot to save Kicad
    [T2601_APIArduinoExtentionBoard.kicad_pcb]
2026-09-07 Commande Aliexpress
    [T2601_APIArduinoExtentionBoard-BOM.xlsx]
2026-09-18 Base support and assembly creation
    [.step, CRYSTAL-SMD_4P-L3.2-W2.5-BL.ipt, C_0402.ipt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]
2026-09-18 Schematic Modification
2026-09-19 switch to atmega328PB
    [.step, T2601_APIArduinoExtentionBoard.kicad_sch]
2026-09-20 kicad modif
    [T2601_APIArduinoExtentionBoard.kicad_sch]
2026-09-21 Creation Connecteur support carte + support etiquette CAO
    [T2601_BaseP30.0002.ipt, T2601_BaseP30.ipt, T2601_BaseP30.obj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]
2026-09-21 Kicad Modification, switch ATMEGA328P to ATMEGA328PB, schematic modification + rerouting, V0 version, no verification
    [T2601_APIArduinoExtentionBoard.kicad_pcb, T2601_APIArduinoExtentionBoard.kicad_sch]
2026-09-22 Switch to 4 layers PCB
    [T2601_APIArduinoExtentionBoard.kicad_pcb]
2026-09-22 Modification Board to 4 layers, finition routing et re organisation des composants (leds statuts condo alim + reset
    [T2601_APIArduinoExtentionBoard.kicad_pcb, T2601_APIArduinoExtentionBoard.kicad_sch]
2026-10-05 Resolution de diversse ISSUE, position UART, Rerouting, modif VIA
    [T2601_APIArduinoExtentionBoard.kicad_pcb, T2601_APIArduinoExtentionBoard.kicad_sch]
2026-10-05 fix issues #6
    [T2601_APIArduinoExtentionBoard.kicad_pcb]
2026-10-05 remplissage plan
    [T2601_APIArduinoExtentionBoard.kicad_pcb]
2026-10-06 Modification Conn
    [T2601_Conn.0001.ipt, T2601_Conn.ipt, T2601_EG.0002.iam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]
2026-10-07 fix plan de GND oscillateur
    [T2601_APIArduinoExtentionBoard.kicad_pcb]
2026-10-08 complement affectation pin uc #17
2026-10-08 add mecanic backup to gitignore
    [T2601_BaseP30.0002.ipt, T2601_Conn.0001.ipt, T2601_EG.0003.iam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]
2026-10-13 Modification des couches selon choix decider
2026-10-13 Modification affectation pin PWM Mezz 1
2026-10-13 Modification issue #20 GND de la led 12V + ajout via entre In.1 et Bot pour la liaison des couches de GND
2026-10-13 Piste de RESET general
2026-10-14 Reorganisation schematic
2026-10-14 modification organisation des dossiers
2026-10-15 Nouveau schematic selon template V1
2026-10-20 Test point GND
2026-10-25 WIP charges carte d'alimentation selon discution

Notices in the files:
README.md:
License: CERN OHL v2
